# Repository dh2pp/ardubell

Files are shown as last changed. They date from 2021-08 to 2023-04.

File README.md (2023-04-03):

# ardubell

ardubell

This project is for people who live in a flat and don't want to carry along their keys when they just leave home for shopping etc. You can simply use the Door bell button and type a pattern (compare Morse Code) and - provided that you have a remote unlock button from inside your flat - get the door unlocked automatically.

Code is working, but not nice :/ Hope to find some time to make it better (interrupt waking up from sleep, ...)

**Disclaimer**: Of course, this is not very secure but may be secure enough for the public front door to the stair case. I thought about a challenge response, but the only channel to transmit the challenge to the person at the front door is unlocking the door ^^ Feel free to share your thoughts/improvements in an issue.

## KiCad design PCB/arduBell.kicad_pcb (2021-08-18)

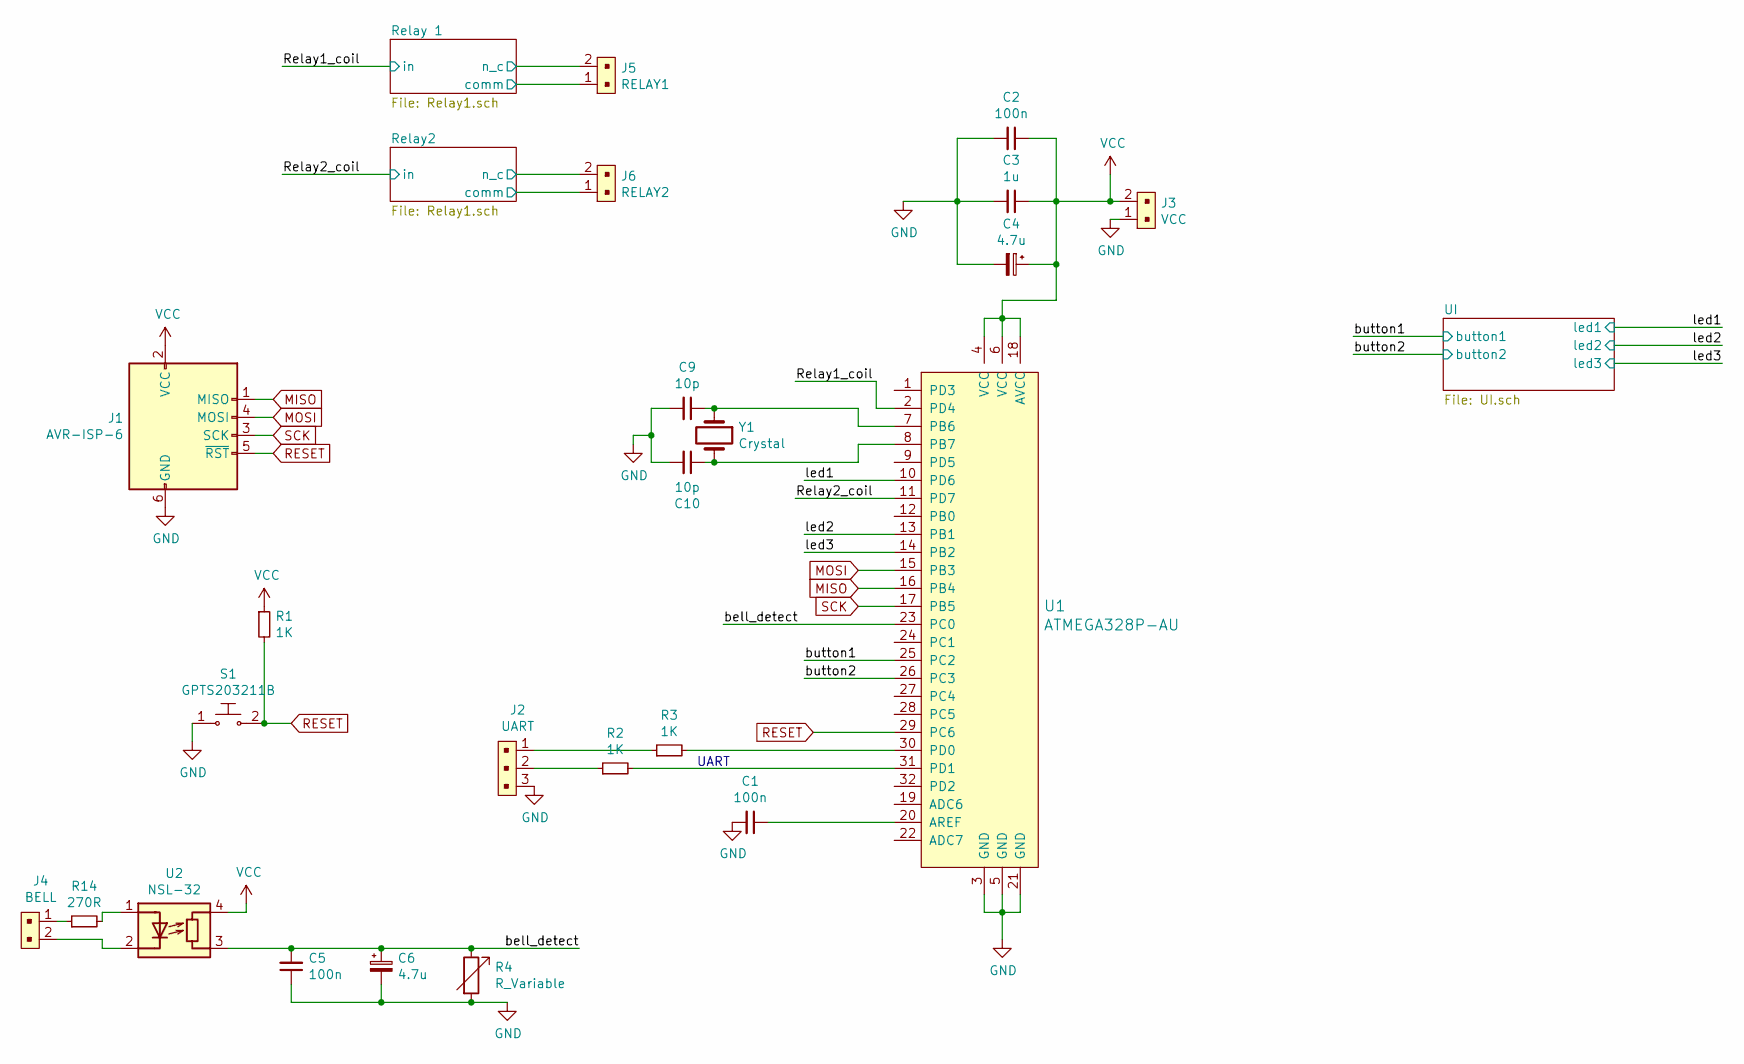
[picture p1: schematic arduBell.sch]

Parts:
C1, C2, C5: 100n; C_0603_1608Metric
C3: 1u; C_0603_1608Metric
C4, C6: 4.7u; C_1206_3216Metric
C9, C10: 10p; C_0603_1608Metric
J1: AVR-ISP-6; PinHeader_2x03_P2.54mm_Horizontal
J2: UART; PinHeader_1x3_P2.54_Drill1.1mm; MPN 640456-3; Digi-Key_PN A19470-ND
J3: VCC; PinHeader_1x2_P2.54mm_Drill1.02mm; MPN 22-23-2021; Digi-Key_PN WM4200-ND
J4: BELL; PinHeader_1x2_P2.54mm_Drill1.02mm; MPN 22-23-2021; Digi-Key_PN WM4200-ND
J5: RELAY1; PinHeader_1x2_P2.54mm_Drill1.02mm; MPN 22-23-2021; Digi-Key_PN WM4200-ND
J6: RELAY2; PinHeader_1x2_P2.54mm_Drill1.02mm; MPN 22-23-2021; Digi-Key_PN WM4200-ND
R1, R2, R3: 1K; R_0603_1608Metric
R4: R_Variable; Potentiometer_Bourns_3386P_Vertical
R14: 270R; R_0603_1608Metric
S1: GPTS203211B; SW_PUSH_6mm; MPN GPTS203211B; Digi-Key_PN CW181-ND
U1: ATMEGA328P-AU; TQFP-32_7x7mm; MPN ATMEGA328P-AU; Digi-Key_PN ATMEGA328P-AU-ND
U2: NSL-32; DIP-4_W8.89mm_SMDSocket_LongPads
Y1: Crystal

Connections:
/Relay1_coil: U1.2 (PD4); also elsewhere on the board
/Relay2/comm: J6.1; also elsewhere on the board
/Relay2/n_c: J6.2; also elsewhere on the board
/Relay2_coil: U1.11 (PD7); also elsewhere on the board
/Relay 1/comm: J5.1; also elsewhere on the board
/Relay 1/n_c: J5.2; also elsewhere on the board
/bell_detect: C5.2, C6.1, R4.1, U1.23 (PC0), U2.3 (R)
/button1: U1.25 (PC2); also elsewhere on the board
/button2: U1.26 (PC3); also elsewhere on the board
/led1: U1.10 (PD6); also elsewhere on the board
/led2: U1.13 (PB1); also elsewhere on the board
/led3: U1.14 (PB2); also elsewhere on the board
GND: C1.2, C2.2, C3.2, C4.2, C5.1, C6.2, C9.2, C10.2, J1.6 (GND), J2.3, J3.1, R4.2, S1.1, U1.3 (GND), U1.5 (GND), U1.21 (GND); also elsewhere on the board
MISO: J1.1 (MISO), U1.16 (PB4)
MOSI: J1.4 (MOSI), U1.15 (PB3)
unnamed: C1.1, U1.20 (AREF)
unnamed: C9.1, U1.7 (PB6), Y1.1
unnamed: C10.1, U1.8 (PB7), Y1.2
unnamed: J2.1, R3.1
unnamed: J2.2, R2.1
unnamed: J4.1, R14.1
unnamed: J4.2, U2.2 (K)
unnamed: R2.2, U1.31 (PD1)
unnamed: R3.2, U1.30 (PD0)
unnamed: R14.2, U2.1 (A)
RESET: J1.5 (~RST), R1.2, S1.2, U1.29 (PC6)
SCK: J1.3 (SCK), U1.17 (PB5)
VCC: C2.1, C3.1, C4.1, J1.2 (VCC), J3.2, R1.1, U1.4 (VCC), U1.6 (VCC), U1.18 (AVCC), U2.4 (R); also elsewhere on the board

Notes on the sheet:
UART

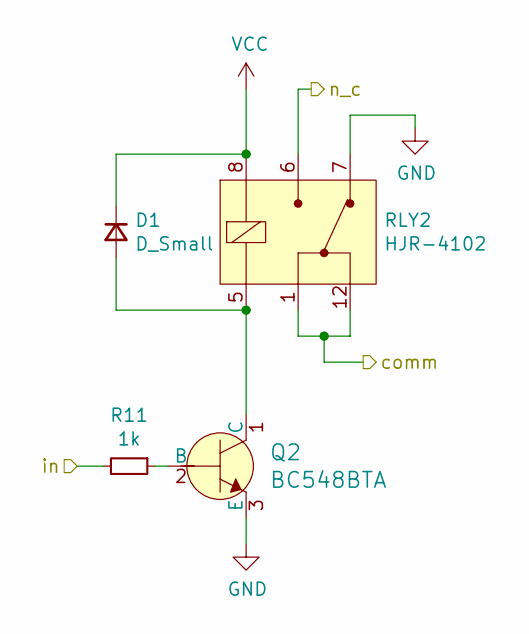
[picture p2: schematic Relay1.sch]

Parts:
D2: D_Small; D_DO-34_SOD68_P7.62mm_Horizontal
Q1: BC548BTA; TO-92L_Inline; MPN BC548BTA; Digi-Key_PN BC548BTACT-ND
R10: 1k; R_0603_1608Metric
RLY1: HJR-4102; Relay_SPDT_HJR-4102

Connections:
/Relay1_coil: R10.2; also elsewhere on the board
/Relay 1/comm: RLY1.1 (COM), RLY1.12 (COM); also elsewhere on the board
/Relay 1/n_c: RLY1.6 (NO); also elsewhere on the board
GND: Q1.3 (E), RLY1.7 (NC); also elsewhere on the board
unnamed: D2.2 (A), Q1.1 (C), RLY1.5 (COIL)
unnamed: Q1.2 (B), R10.1
VCC: D2.1 (K), RLY1.8 (COIL); also elsewhere on the board

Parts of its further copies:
D1: D_Small; D_DO-34_SOD68_P7.62mm_Horizontal
Q2: BC548BTA; TO-92L_Inline; MPN BC548BTA; Digi-Key_PN BC548BTACT-ND
R11: 1k; R_0603_1608Metric
RLY2: HJR-4102; Relay_SPDT_HJR-4102

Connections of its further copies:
/Relay2/comm: RLY2.1 (COM), RLY2.12 (COM); also elsewhere on the board
/Relay2/n_c: RLY2.6 (NO); also elsewhere on the board
/Relay2_coil: R11.2; also elsewhere on the board
GND: Q2.3 (E), RLY2.7 (NC); also elsewhere on the board
unnamed: D1.2 (A), Q2.1 (C), RLY2.5 (COIL)
unnamed: Q2.2 (B), R11.1
VCC: D1.1 (K), RLY2.8 (COIL); also elsewhere on the board

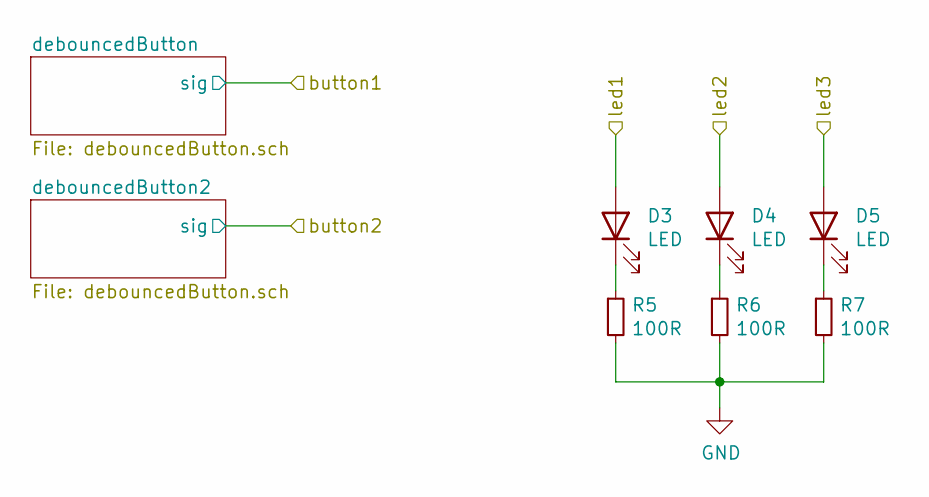
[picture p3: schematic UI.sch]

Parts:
D3, D4, D5: LED; LED_D5.0mm
R5, R6, R7: 100R; R_0603_1608Metric

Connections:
/led1: D3.2 (A); also elsewhere on the board
/led2: D4.2 (A); also elsewhere on the board
/led3: D5.2 (A); also elsewhere on the board
GND: R5.2, R6.2, R7.2; also elsewhere on the board
unnamed: D3.1 (K), R5.1
unnamed: D4.1 (K), R6.1
unnamed: D5.1 (K), R7.1

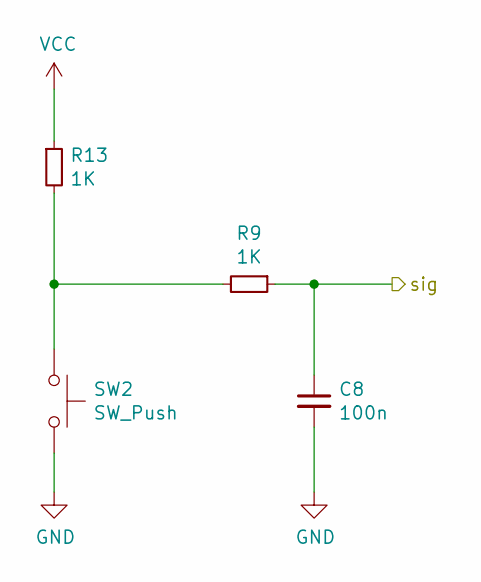
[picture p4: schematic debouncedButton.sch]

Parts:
C7: 100n; C_0603_1608Metric
R8, R12: 1K; R_0603_1608Metric
SW1: SW_Push; SW_PUSH_6mm

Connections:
/button1: C7.1, R8.1; also elsewhere on the board
GND: C7.2, SW1.2; also elsewhere on the board
unnamed: R8.2, R12.2, SW1.1
VCC: R12.1; also elsewhere on the board

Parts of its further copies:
C8: 100n; C_0603_1608Metric
R9, R13: 1K; R_0603_1608Metric
SW2: SW_Push; SW_PUSH_6mm

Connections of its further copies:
/button2: C8.1, R9.1; also elsewhere on the board
GND: C8.2, SW2.2; also elsewhere on the board
unnamed: R9.2, R13.2, SW2.1
VCC: R13.1; also elsewhere on the board

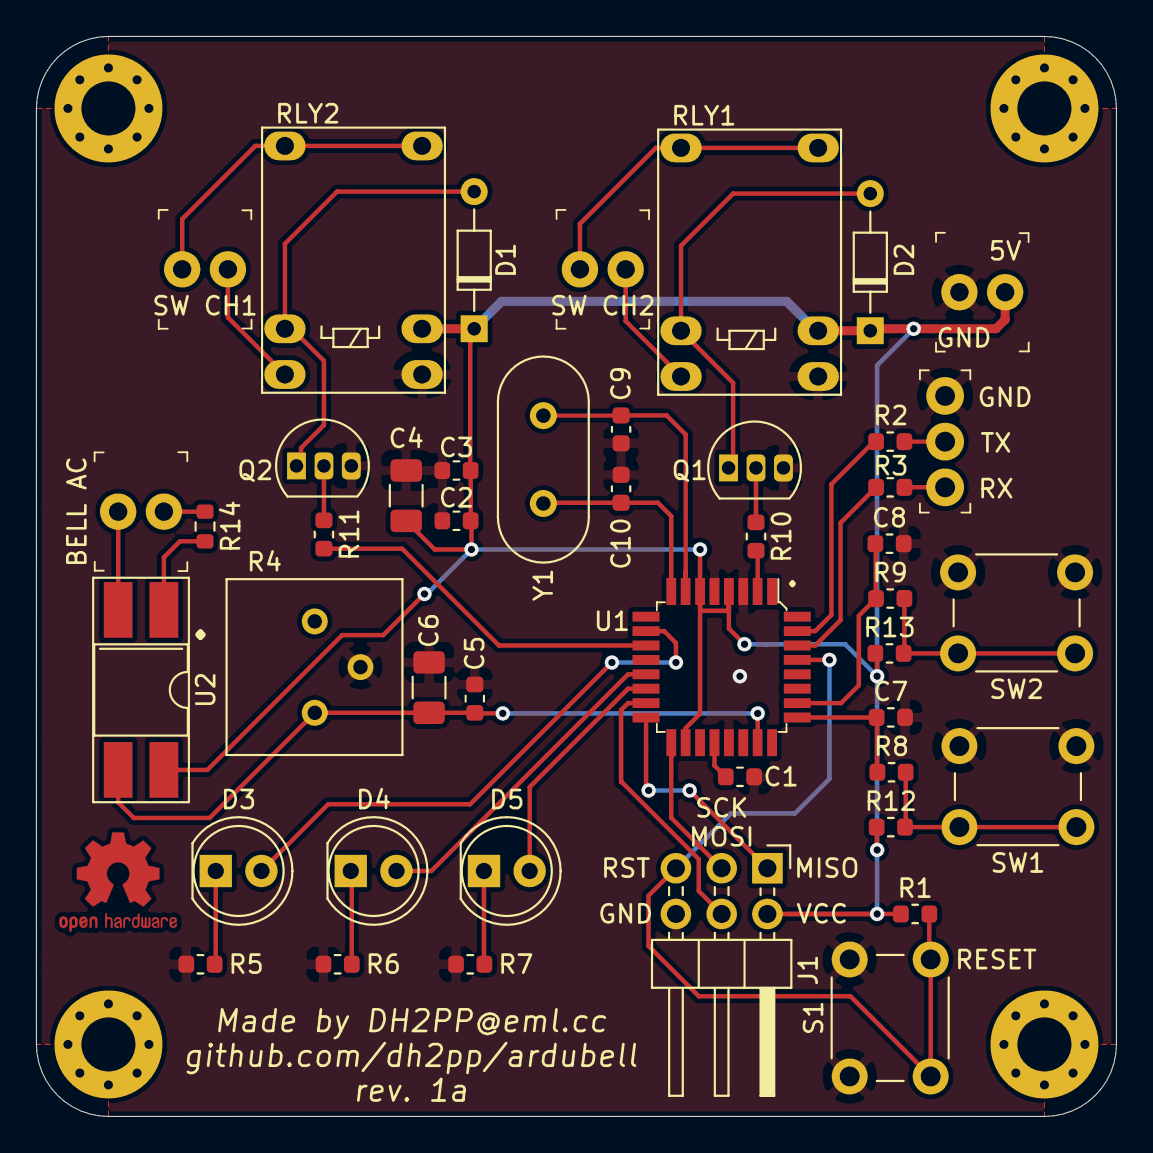
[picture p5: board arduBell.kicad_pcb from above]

Board: 2 copper layers, 60.0 x 60.0 mm, 49 parts (0 on the bottom side), 37 nets.

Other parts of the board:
 : MountingHole_3mm_Pad_Via
 #2,  #3,  #4: MountingHole_3mm_Pad_Via

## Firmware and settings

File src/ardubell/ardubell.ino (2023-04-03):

// https://www.teachmemicro.com/arduino-state-machine-tutorial/
// https://github.com/kurimawxx00/FiniteStateMachine/
// https://playground.arduino.cc/Code/FiniteStateMachine/

#include <stdio.h>
#include <stdbool.h>

#include "FiniteStateMachine.h"


#define ledPin1 6
#define ledPin2 9
#define ledPin3 10
#define relay1 4
#define relay2 7
#define button1 A2
#define button2 A3
#define belldetect A0

const unsigned long timeout_inter_character = 500;
const unsigned long debounce_millis = 20;

State WAIT_BELL = State(wait_bell);
State DETECT_PATTERN = State(detect_pattern);
State UNLOCK = State(unlock);
State RING = State(ring);

FSM fsm = FSM(WAIT_BELL);

const int code[4][2] = {{10,200},
                  {400,5000},
                  {400,5000},
                  {10,300},};


void setup() {
    pinMode(ledPin1,    OUTPUT);
    pinMode(ledPin2,    OUTPUT);
    pinMode(ledPin3,    OUTPUT);
    pinMode(relay1,     OUTPUT);
    pinMode(relay2,     OUTPUT);
    pinMode(button1,    INPUT);
    pinMode(button2,    INPUT);
    pinMode(belldetect, INPUT);
}

// assumes, that bell is released, enters after bouncing
void wait_bell() {
    digitalWrite(ledPin1, LOW);
    unsigned long i = 0;
    int led = 1;
    unsigned long t_inter = 0;

    while (true) {
        ++i;
        if (i%1000 == 0) {
            led = !led;
            digitalWrite(ledPin3, !led);
            digitalWrite(ledPin2, led);
        }

        t_inter = millis();
        delay(1);
        while (digitalRead(belldetect) == HIGH && millis() - t_inter < debounce_millis) {
            digitalWrite(ledPin1, HIGH);
            digitalWrite(ledPin2, LOW);
            digitalWrite(ledPin3, LOW);
            delay(1);
        }
        if (digitalRead(belldetect) == HIGH) {
            digitalWrite(ledPin1, HIGH);
            fsm.transitionTo(DETECT_PATTERN);
            break;
        }
    }
}

// transition state with branching: unlock, ring or go back to idle?
// assumes, that bell is pressed, enters after bouncing
void detect_pattern() {
    unsigned long t_inter = 0;
    unsigned long t0 = 0;
    unsigned long t_i = 0;
    unsigned long remaining_code_length = 0;
    digitalWrite(ledPin1, LOW);
    digitalWrite(ledPin2, LOW);
    digitalWrite(ledPin3, LOW);
    
    bool pattern_correct = true;
    //iterate over the characters breaks out in case of wrong patten into ring
    for (int i = 0; i < 3; ++i) {
        if (!pattern_correct) {
            fsm.transitionTo(RING);
            break;
        }

        if (digitalRead(belldetect) == HIGH) {
            delay(code[i][0]);
            if (digitalRead(belldetect) == LOW) {
                pattern_correct = false;
                fsm.transitionTo(RING);
                break;
            }
            if (!pattern_correct) {
              fsm.transitionTo(RING);
              break;
            }
            // HIGH waiting to become debounced LOW
            t_inter = millis();
            t0 = millis();
            t_i = 0;

            remaining_code_length = code[i][1] - code[i][0];
            while (digitalRead(belldetect) == HIGH || millis() - t_inter < debounce_millis) {
                delay(1);
                t_i = millis();
                if (digitalRead(belldetect) == HIGH) t_inter = t_i;
                else if (t_i - t_inter > debounce_millis) {
                    break;
                }
                if (t_i - t0 > remaining_code_length) {
                    pattern_correct = false;
                    fsm.transitionTo(RING);
                    break;
                }
            }

            digitalWrite(ledPin2, HIGH);
            t_inter = millis();
            t0 = millis();
            // LOW waiting to become debounced HIGH
            while (digitalRead(belldetect) == LOW || millis() - t_inter < debounce_millis) {
                delay(1);
                t_i = millis();
                if (digitalRead(belldetect) == LOW) t_inter = t_i;
                else if (t_i - t_inter > debounce_millis) {
                    break;
                }
                if (t_i - t0 > timeout_inter_character) {
                    pattern_correct = false;
                    fsm.transitionTo(RING);
                    break;
                }
            }
            digitalWrite(ledPin2, LOW);
        }
    }
    if (pattern_correct) fsm.transitionTo(UNLOCK);
    else fsm.transitionTo(RING);
}


void ring() {
  //strobo();
    digitalWrite(relay1, HIGH);
    delay(300);
    digitalWrite(relay1, LOW);
    delay(1000);
    fsm.transitionTo(WAIT_BELL);
}

void unlock() {
    digitalWrite(relay2, HIGH);
    delay(1200);
    digitalWrite(relay2, LOW);

    for (int i=0; i<8; ++i){
        digitalWrite(ledPin1, HIGH);
        delay(300);
        digitalWrite(ledPin1, LOW);
    }

    fsm.transitionTo(WAIT_BELL);
}

void loop()
{
    // Call fsm run
    fsm.update();
    
}

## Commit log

2021-03-10 1st check
    [arduBell-B_Cu.gbr, arduBell-B_Mask.gbr, arduBell-B_Paste.gbr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]
2021-05-10 rev 1a, XO fixed, more labels and rearranging
    [Relay1.sch, UI.sch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]
2021-08-18 rev 1a: optocoupler works, quarz works
    [arduBell.kicad_pcb, arduBell.sch]
2023-04-03 inital SW commit
    [Relay1.sch, UI.sch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]
